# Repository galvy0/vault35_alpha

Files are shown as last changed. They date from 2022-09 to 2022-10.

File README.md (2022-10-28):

# Vault35 Alpha Stagger PCB
Alpha stagger version of Cain's Vault35 keyboard.  
Check out the original product and other awesome projects of Cain at [https://mechvault.net/](https://mechvault.net/).  

## PCB
### Layout Options
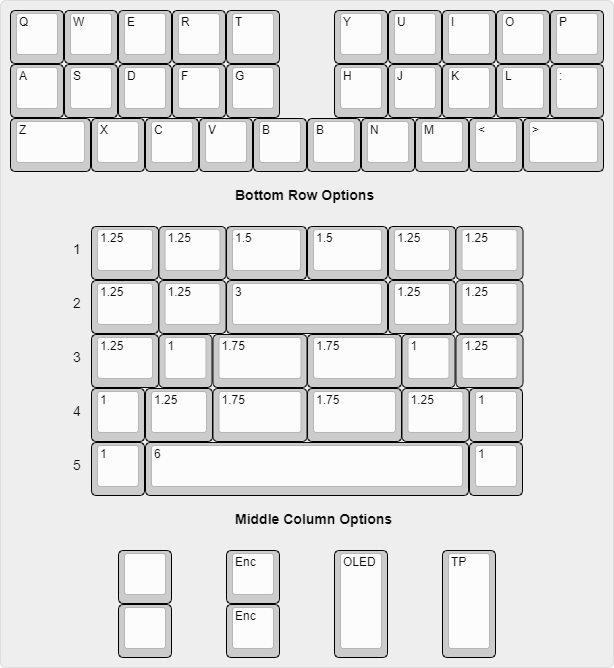
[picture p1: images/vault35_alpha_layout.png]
Layouts


### Middle Column Options
There are four options to fill in the space in the middle column: 1) two normal switches, 2) two encoders (or a combination of encoders and normal switches), 3) an OLED, and 4) a trackpoint module.  
For TP option, refer to my phoenix45 alpha stagger repo: https://github.com/galvy0/phoenix45_alpha

## Firmware
https://github.com/galvy0/qmk_firmware/tree/galvy/keyboards/galvy/vault35_alpha

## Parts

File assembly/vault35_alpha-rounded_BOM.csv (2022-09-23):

Id | Designator | Package | Quantity | Designation | Supplier and ref
1 | K_SPACE4,K_SPACE17,K_SPACE30,K_SPACE9,K_SPACE21,K_SPACE15,K_SPACE44,K_SPACE10,K_SPACE2,K_SPACE47,K_SPACE14,K_SPACE32,K_SPACE26,K_SPACE25,K_SPACE8,K_SPACE43,K_SPACE20,K_SPACE48,K_SPACE11,K_SPACE19,K_SPACE16,K_SPACE12,K_SPACE22,K_SPACE3,K_SPACE7,K_SPACE6,K_SPACE29,K_SPACE5,K_SPACE27,K_SPACE24,K_SPACE18,K_SPACE31,K_SPACE1,K_SPACE13 | MXOnly-1U-NoLED | 34 | KEYSW
2 | SW5 | PinHeader_1x02_P2.54mm_Vertical | 1 | SW_PUSH
3 | K_SPACE28,K_SPACE33,K_SPACE39,K_SPACE23 | MXOnly-1.5U-NoLED | 4 | KEYSW
4 | K_SPACE37,K_SPACE41,K_SPACE34,K_SPACE36,K_SPACE38,K_SPACE42 | MXOnly-1.25U-NoLED | 6 | KEYSW
5 | K_SPACE40 | MXOnly-3U-ReversedStabilizers-NoSwitch | 1 | KEYSW
6 | SW2,SW3 | RotaryEncoder_Alps_EC11E-Switch_Vertical_H20mm | 2 | RotaryEncoder_Switch
7 | SW6,SW1 | SW_SPST_SKQG_WithoutStem | 2 | SW_PUSH
8 | K_SPACE45,K_SPACE35 | MXOnly-1.75U-NoLED | 2 | KEYSW
9 | K_SPACE46 | MXOnly-6U-Centered-ReversedStabilizers-NoLED | 1 | KEYSW
10 | OL1 | OLED_v2 | 1 | OLED
11 | D_SPACE17,D_SPACE34,D_SPACE5,D_SPACE1,D_SPACE32,D_SPACE36,D_SPACE38,D_SPACE25,D_SPACE18,D_SPACE9,D_SPACE13,D_SPACE35,D_SPACE12,D_SPACE29,D_SPACE2,D_SPACE20,D_SPACE24,D_SPACE21,D_SPACE15,D_SPACE26,D_SPACE16,D_SPACE14,D_SPACE30,D_SPACE4,D_SPACE11,D_SPACE10,D_SPACE40,D_SPACE8,D_SPACE39,D_SPACE3,D_SPACE27,D_SPACE23,D_SPACE31,D_SPACE7,D_SPACE33,D_SPACE19,D_SPACE22,D_SPACE6 | D_SOD-123 | 38 | D
12 | X1 | Crystal_SMD_3225-4Pin_3.2x2.5mm_HandSoldering | 1 | Crystal_GND24_Small
13 | TP1 | TestPoint_THTPad_1.0x1.0mm_Drill0.5mm | 1 | TPCLK
14 | U1 | SOT-23-6 | 1 | SRV05-4
15 | UR5 | R_0805_2012Metric | 1 | 1M
16 | F1 | Fuse_1206_3216Metric_Pad1.42x1.75mm_HandSolder | 1 | Polyfuse_Small
17 | TP4 | TestPoint_THTPad_1.0x1.0mm_Drill0.5mm | 1 | TPDATA
18 | UR3,UR4 | R_0805_2012Metric | 2 | 5.1k
19 | U2 | QFN-44-1EP_7x7mm_P0.5mm_EP5.2x5.2mm_ThermalVias | 1 | ATmega32U4-M
20 | C2,C1 | C_0805_2012Metric | 2 | 22p
21 | C4 | C_0805_2012Metric | 1 | 10uF
22 | C10 | C_0805_2012Metric_Pad1.18x1.45mm_HandSolder | 1 | 2.2uF
23 | TP2 | TestPoint_THTPad_1.0x1.0mm_Drill0.5mm | 1 | TPVCC
24 | TP3 | TestPoint_THTPad_1.0x1.0mm_Drill0.5mm | 1 | TPGND
25 | UR1,UR2 | R_0805_2012Metric | 2 | 22
26 | R2,R1 | R_0805_2012Metric | 2 | 10k
27 | TP5 | TestPoint_THTPad_1.0x1.0mm_Drill0.5mm | 1 | TPRST
28 | UR8 | R_0805_2012Metric_Pad1.20x1.40mm_HandSolder | 1 | 100k
29 | C6,C8,C5,C7 | C_0805_2012Metric | 4 | 0.1uf
30 | UR7,UR6 | R_0805_2012Metric_Pad1.20x1.40mm_HandSolder | 2 | 4.7k
31 | C3 | C_0805_2012Metric | 1 | 1uf
32 | C9 | C_0805_2012Metric | 1 | 4.7uF
33 | USB1 | HRO-TYPE-C-31-M-12-HandSoldering | 1 | HRO-TYPE-C-31-M-12
34 | J1 | IDC-Header_2x03_P2.54mm_Vertical | 1 | AVR-ISP-6

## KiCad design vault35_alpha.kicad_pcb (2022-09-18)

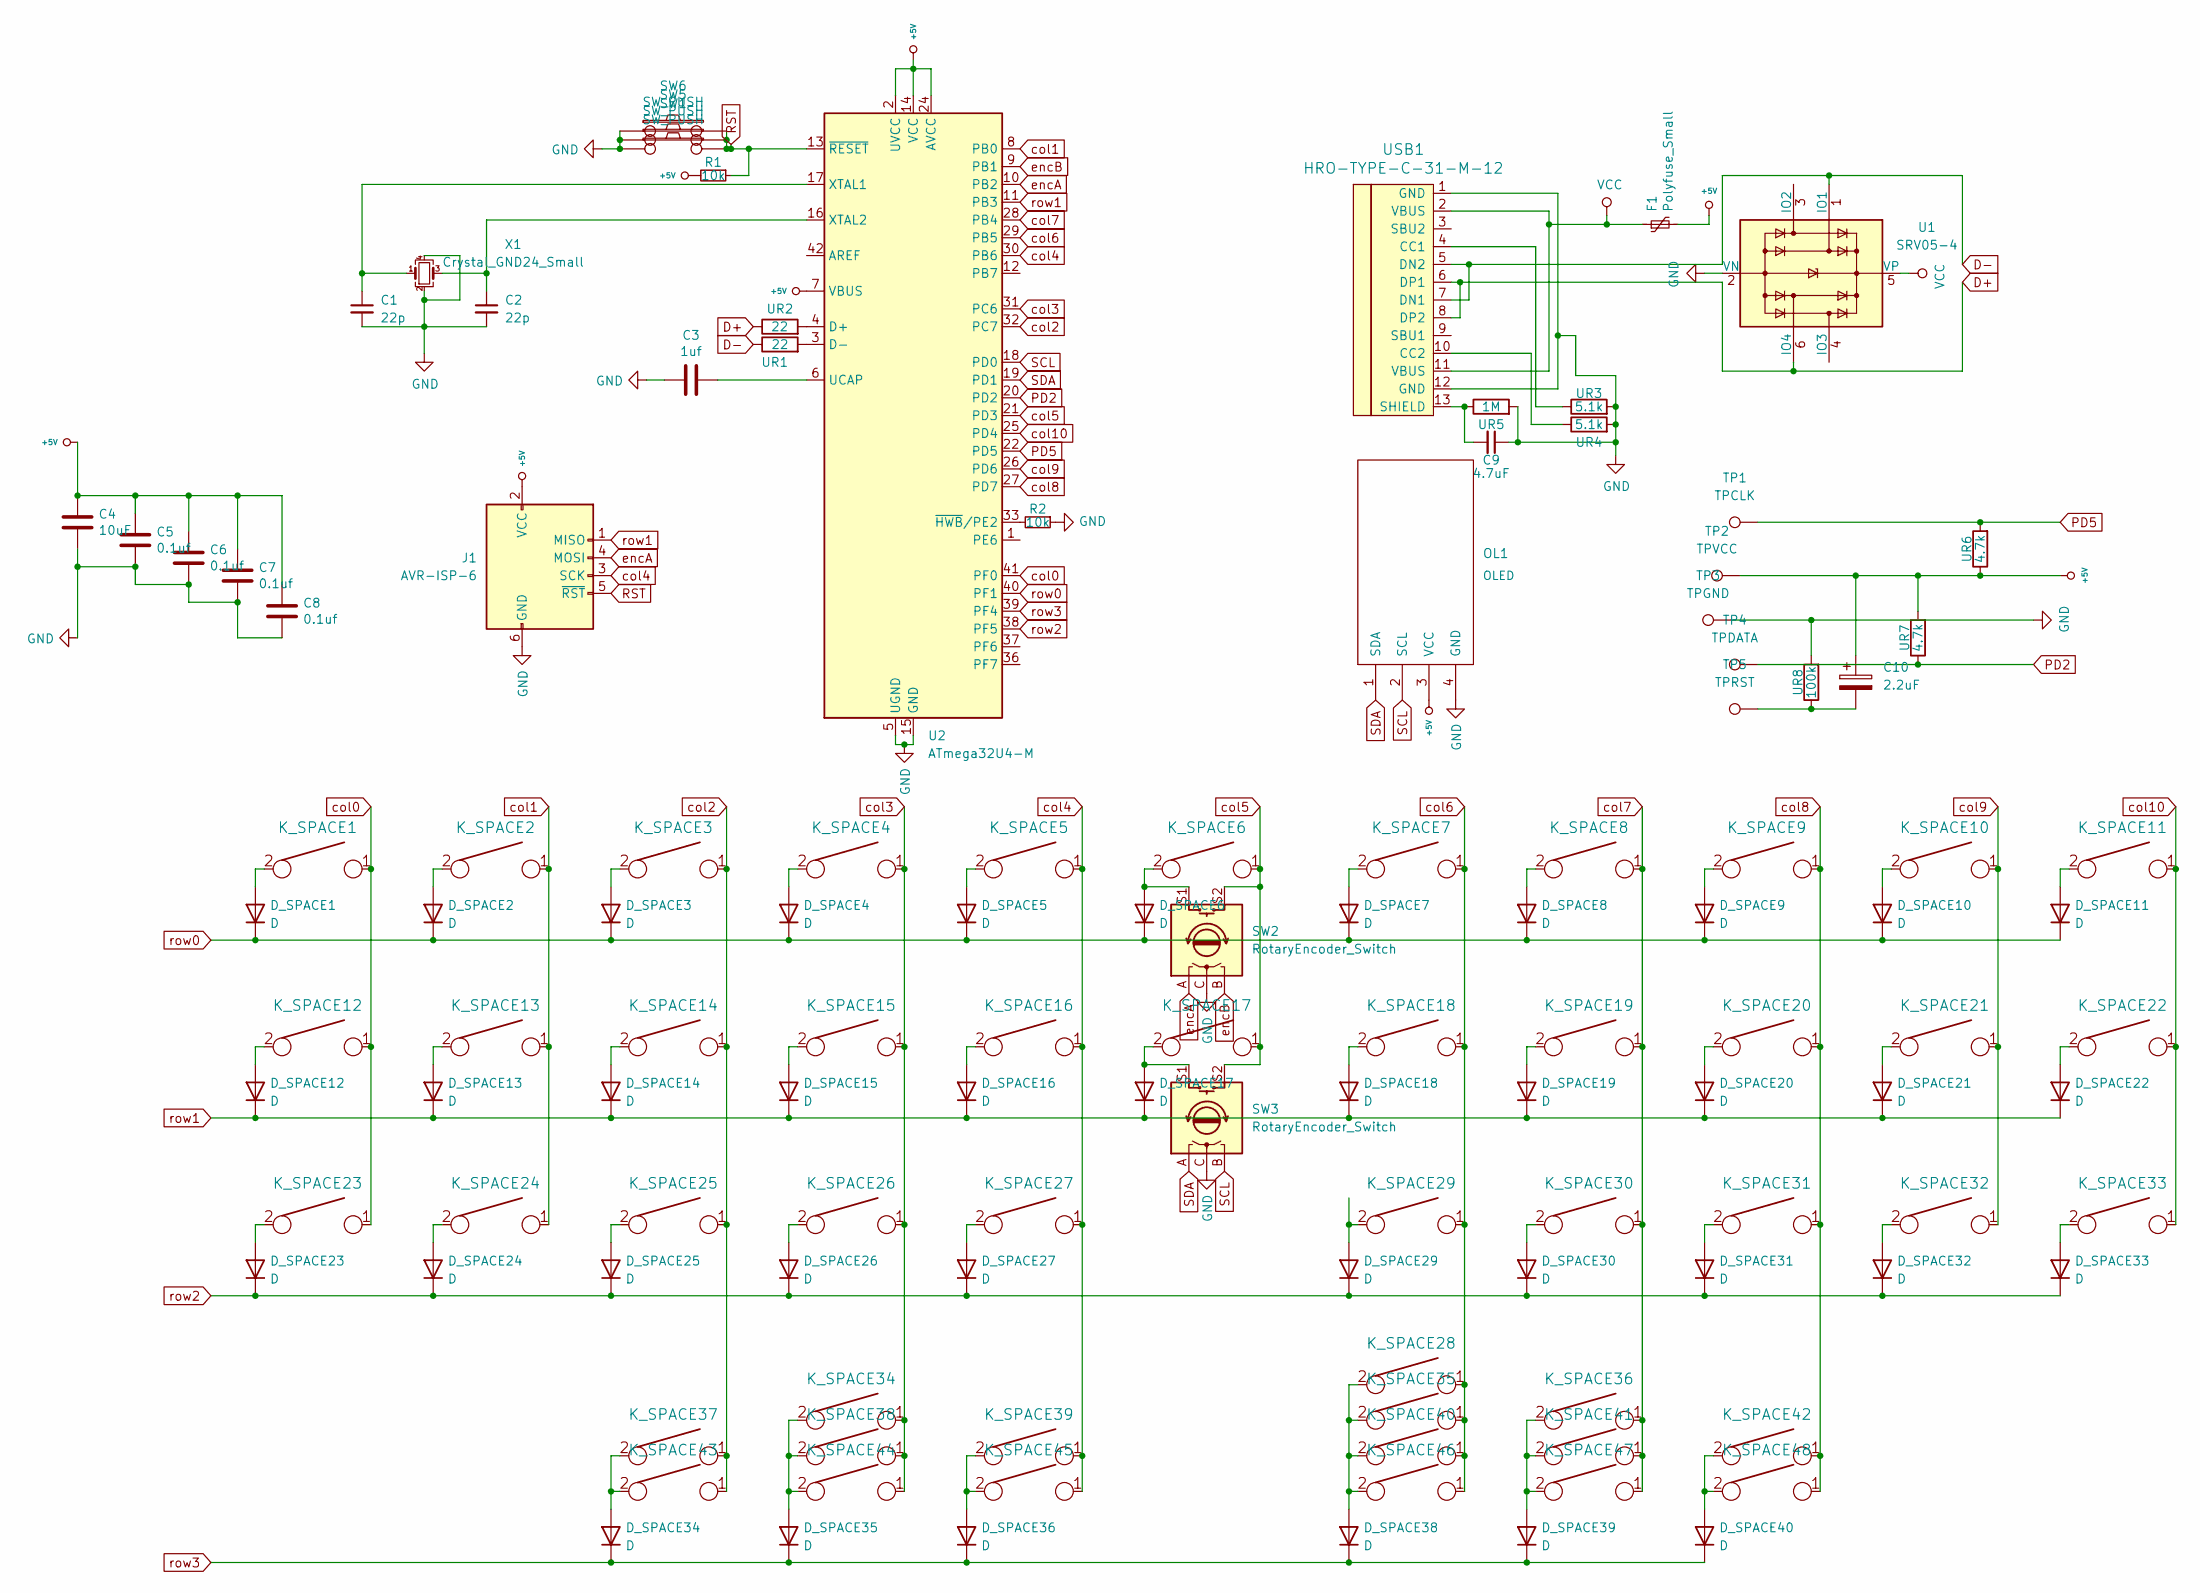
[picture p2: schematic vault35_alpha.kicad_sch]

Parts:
C1, C2: 22p; C_0805_2012Metric
C3: 1uf; C_0805_2012Metric
C4: 10uF; C_0805_2012Metric
C5, C6, C7, C8: 0.1uf; C_0805_2012Metric
C9: 4.7uF; C_0805_2012Metric
C10: 2.2uF; C_0805_2012Metric_Pad1.18x1.45mm_HandSolder
D_SPACE1, D_SPACE2, D_SPACE3, D_SPACE4, D_SPACE5, D_SPACE6, D_SPACE7, D_SPACE8, D_SPACE9, D_SPACE10, D_SPACE11, D_SPACE12, D_SPACE13, D_SPACE14, D_SPACE15, D_SPACE16, D_SPACE17, D_SPACE18, D_SPACE19, D_SPACE20, D_SPACE21, D_SPACE22, D_SPACE23, D_SPACE24, D_SPACE25, D_SPACE26, D_SPACE27, D_SPACE29, D_SPACE30, D_SPACE31, D_SPACE32, D_SPACE33, D_SPACE34, D_SPACE35, D_SPACE36, D_SPACE38, D_SPACE39, D_SPACE40: D; D_SOD-123
F1: Polyfuse_Small; Fuse_1206_3216Metric_Pad1.42x1.75mm_HandSolder
J1: AVR-ISP-6; IDC-Header_2x03_P2.54mm_Vertical
K_SPACE1, K_SPACE2, K_SPACE3, K_SPACE4, K_SPACE5, K_SPACE6, K_SPACE7, K_SPACE8, K_SPACE9, K_SPACE10, K_SPACE11, K_SPACE12, K_SPACE13, K_SPACE14, K_SPACE15, K_SPACE16, K_SPACE17, K_SPACE18, K_SPACE19, K_SPACE20, K_SPACE21, K_SPACE22, K_SPACE24, K_SPACE25, K_SPACE26, K_SPACE27, K_SPACE29, K_SPACE30, K_SPACE31, K_SPACE32, K_SPACE43, K_SPACE44, K_SPACE47, K_SPACE48: KEYSW; MXOnly-1U-NoLED
K_SPACE23, K_SPACE28, K_SPACE33, K_SPACE39: KEYSW; MXOnly-1.5U-NoLED
K_SPACE34, K_SPACE36, K_SPACE37, K_SPACE38, K_SPACE41, K_SPACE42: KEYSW; MXOnly-1.25U-NoLED
K_SPACE35, K_SPACE45: KEYSW; MXOnly-1.75U-NoLED
K_SPACE40: KEYSW; MXOnly-3U-ReversedStabilizers-NoSwitch
K_SPACE46: KEYSW; MXOnly-6U-Centered-ReversedStabilizers-NoLED
OL1: OLED; OLED_v2
R1, R2: 10k; R_0805_2012Metric
SW1, SW6: SW_PUSH; SW_SPST_SKQG_WithoutStem
SW2, SW3: RotaryEncoder_Switch; RotaryEncoder_Alps_EC11E-Switch_Vertical_H20mm
SW5: SW_PUSH; PinHeader_1x02_P2.54mm_Vertical
TP1: TPCLK; TestPoint_THTPad_1.0x1.0mm_Drill0.5mm
TP2: TPVCC; TestPoint_THTPad_1.0x1.0mm_Drill0.5mm
TP3: TPGND; TestPoint_THTPad_1.0x1.0mm_Drill0.5mm
TP4: TPDATA; TestPoint_THTPad_1.0x1.0mm_Drill0.5mm
TP5: TPRST; TestPoint_THTPad_1.0x1.0mm_Drill0.5mm
U1: SRV05-4; SOT-23-6
U2: ATmega32U4-M; QFN-44-1EP_7x7mm_P0.5mm_EP5.2x5.2mm_ThermalVias
UR1, UR2: 22; R_0805_2012Metric
UR3, UR4: 5.1k; R_0805_2012Metric
UR5: 1M; R_0805_2012Metric
UR6, UR7: 4.7k; R_0805_2012Metric_Pad1.20x1.40mm_HandSolder
UR8: 100k; R_0805_2012Metric_Pad1.20x1.40mm_HandSolder
USB1: HRO-TYPE-C-31-M-12; HRO-TYPE-C-31-M-12-HandSoldering
X1: Crystal_GND24_Small; Crystal_SMD_3225-4Pin_3.2x2.5mm_HandSoldering

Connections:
+5V: C4.1, C5.1, C6.1, C7.1, C8.1, C10.1, F1.2, J1.2 (VCC), OL1.3 (VCC), R1.2, TP2.1, U2.2 (UVCC), U2.7 (VBUS), U2.14 (VCC), U2.24 (AVCC), U2.34 (VCC), U2.44 (AVCC), UR6.1, UR7.2
D+: U1.6 (IO4), UR1.1, USB1.6 (DP1), USB1.8 (DP2)
D-: U1.1 (IO1), UR2.1, USB1.5 (DN2), USB1.7 (DN1)
GND: C1.2, C2.2, C3.2, C4.2, C5.2, C6.2, C7.2, C8.2, C9.1, J1.6 (GND), OL1.4 (GND), R2.1, SW1.1, SW2.C, SW3.C, SW5.1, SW6.1, TP3.1, U1.2 (VN), U2.5 (UGND), U2.15 (GND), U2.23 (GND), U2.35 (GND), U2.43 (GND), U2.45 (GND), UR3.2, UR4.2, UR5.2, UR8.2, USB1.1 (GND), USB1.12 (GND), X1.2, X1.4
unnamed: C1.1, U2.17 (XTAL1), X1.1
unnamed: C2.1, U2.16 (XTAL2), X1.3
unnamed: C3.1, U2.6 (UCAP)
unnamed: C9.2, UR5.1, USB1.13 (SHIELD)
unnamed: C10.2, TP5.1, UR8.1
unnamed: D_SPACE1.2 (A), K_SPACE1.2
unnamed: D_SPACE2.2 (A), K_SPACE2.2
unnamed: D_SPACE3.2 (A), K_SPACE3.2
unnamed: D_SPACE4.2 (A), K_SPACE4.2
unnamed: D_SPACE5.2 (A), K_SPACE5.2
unnamed: D_SPACE6.2 (A), K_SPACE6.2, SW2.S1
unnamed: D_SPACE7.2 (A), K_SPACE7.2
unnamed: D_SPACE8.2 (A), K_SPACE8.2
unnamed: D_SPACE9.2 (A), K_SPACE9.2
unnamed: D_SPACE10.2 (A), K_SPACE10.2
unnamed: D_SPACE11.2 (A), K_SPACE11.2
unnamed: D_SPACE12.2 (A), K_SPACE12.2
unnamed: D_SPACE13.2 (A), K_SPACE13.2
unnamed: D_SPACE14.2 (A), K_SPACE14.2
unnamed: D_SPACE15.2 (A), K_SPACE15.2
unnamed: D_SPACE16.2 (A), K_SPACE16.2
unnamed: D_SPACE17.2 (A), K_SPACE17.2, SW3.S1
unnamed: D_SPACE18.2 (A), K_SPACE18.2
unnamed: D_SPACE19.2 (A), K_SPACE19.2
unnamed: D_SPACE20.2 (A), K_SPACE20.2
unnamed: D_SPACE21.2 (A), K_SPACE21.2
unnamed: D_SPACE22.2 (A), K_SPACE22.2
unnamed: D_SPACE23.2 (A), K_SPACE23.2
unnamed: D_SPACE24.2 (A), K_SPACE24.2
unnamed: D_SPACE25.2 (A), K_SPACE25.2
unnamed: D_SPACE26.2 (A), K_SPACE26.2
unnamed: D_SPACE27.2 (A), K_SPACE27.2
unnamed: D_SPACE29.2 (A), K_SPACE29.2
unnamed: D_SPACE30.2 (A), K_SPACE30.2
unnamed: D_SPACE31.2 (A), K_SPACE31.2
unnamed: D_SPACE32.2 (A), K_SPACE32.2
unnamed: D_SPACE33.2 (A), K_SPACE33.2
unnamed: D_SPACE34.2 (A), K_SPACE37.2, K_SPACE43.2
unnamed: D_SPACE35.2 (A), K_SPACE34.2, K_SPACE38.2, K_SPACE44.2
unnamed: D_SPACE36.2 (A), K_SPACE39.2, K_SPACE45.2
unnamed: D_SPACE38.2 (A), K_SPACE28.2, K_SPACE35.2, K_SPACE40.2, K_SPACE46.2
unnamed: D_SPACE39.2 (A), K_SPACE36.2, K_SPACE41.2, K_SPACE47.2
unnamed: D_SPACE40.2 (A), K_SPACE42.2, K_SPACE48.2
unnamed: R2.2, U2.33 (~HWB/PE2)
unnamed: U2.3 (D-), UR2.2
unnamed: U2.4 (D+), UR1.2
unnamed: UR3.1, USB1.4 (CC1)
unnamed: UR4.1, USB1.10 (CC2)
PD2: TP4.1, U2.20 (PD2), UR7.1
PD5: TP1.1, U2.22 (PD5), UR6.2
RST: J1.5 (~RST), R1.1, SW1.2, SW5.2, SW6.2, U2.13 (~RESET)
SCL: OL1.2 (SCL), SW3.B, U2.18 (PD0)
SDA: OL1.1 (SDA), SW3.A, U2.19 (PD1)
VCC: F1.1, U1.5 (VP), USB1.2 (VBUS), USB1.11 (VBUS)
col0: K_SPACE1.1, K_SPACE12.1, K_SPACE23.1, U2.41 (PF0)
col1: K_SPACE2.1, K_SPACE13.1, K_SPACE24.1, U2.8 (PB0)
col2: K_SPACE3.1, K_SPACE14.1, K_SPACE25.1, K_SPACE37.1, K_SPACE43.1, U2.32 (PC7)
col3: K_SPACE4.1, K_SPACE15.1, K_SPACE26.1, K_SPACE34.1, K_SPACE38.1, K_SPACE44.1, U2.31 (PC6)
col4: J1.3 (SCK), K_SPACE5.1, K_SPACE16.1, K_SPACE27.1, K_SPACE39.1, K_SPACE45.1, U2.30 (PB6)
col5: K_SPACE6.1, K_SPACE17.1, SW2.S2, SW3.S2, U2.21 (PD3)
col6: K_SPACE7.1, K_SPACE18.1, K_SPACE28.1, K_SPACE29.1, K_SPACE35.1, K_SPACE40.1, K_SPACE46.1, U2.29 (PB5)
col7: K_SPACE8.1, K_SPACE19.1, K_SPACE30.1, K_SPACE36.1, K_SPACE41.1, K_SPACE47.1, U2.28 (PB4)
col8: K_SPACE9.1, K_SPACE20.1, K_SPACE31.1, K_SPACE42.1, K_SPACE48.1, U2.27 (PD7)
col9: K_SPACE10.1, K_SPACE21.1, K_SPACE32.1, U2.26 (PD6)
col10: K_SPACE11.1, K_SPACE22.1, K_SPACE33.1, U2.25 (PD4)
encA: J1.4 (MOSI), SW2.A, U2.10 (PB2)
encB: SW2.B, U2.9 (PB1)
row0: D_SPACE1.1 (K), D_SPACE2.1 (K), D_SPACE3.1 (K), D_SPACE4.1 (K), D_SPACE5.1 (K), D_SPACE6.1 (K), D_SPACE7.1 (K), D_SPACE8.1 (K), D_SPACE9.1 (K), D_SPACE10.1 (K), D_SPACE11.1 (K), U2.40 (PF1)
row1: D_SPACE12.1 (K), D_SPACE13.1 (K), D_SPACE14.1 (K), D_SPACE15.1 (K), D_SPACE16.1 (K), D_SPACE17.1 (K), D_SPACE18.1 (K), D_SPACE19.1 (K), D_SPACE20.1 (K), D_SPACE21.1 (K), D_SPACE22.1 (K), J1.1 (MISO), U2.11 (PB3)
row2: D_SPACE23.1 (K), D_SPACE24.1 (K), D_SPACE25.1 (K), D_SPACE26.1 (K), D_SPACE27.1 (K), D_SPACE29.1 (K), D_SPACE30.1 (K), D_SPACE31.1 (K), D_SPACE32.1 (K), D_SPACE33.1 (K), U2.38 (PF5)
row3: D_SPACE34.1 (K), D_SPACE35.1 (K), D_SPACE36.1 (K), D_SPACE38.1 (K), D_SPACE39.1 (K), D_SPACE40.1 (K), U2.39 (PF4)

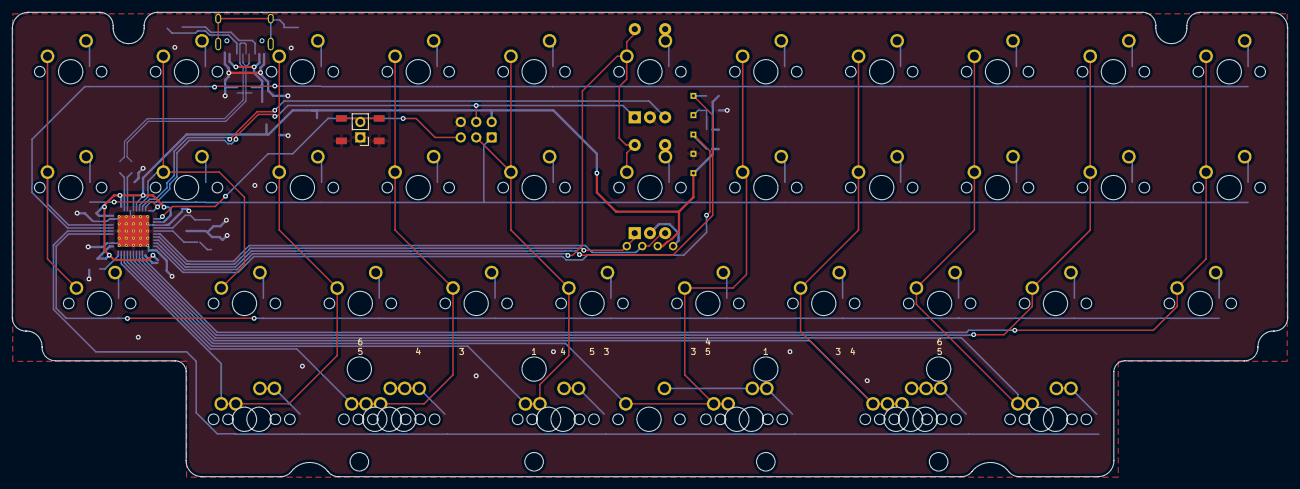
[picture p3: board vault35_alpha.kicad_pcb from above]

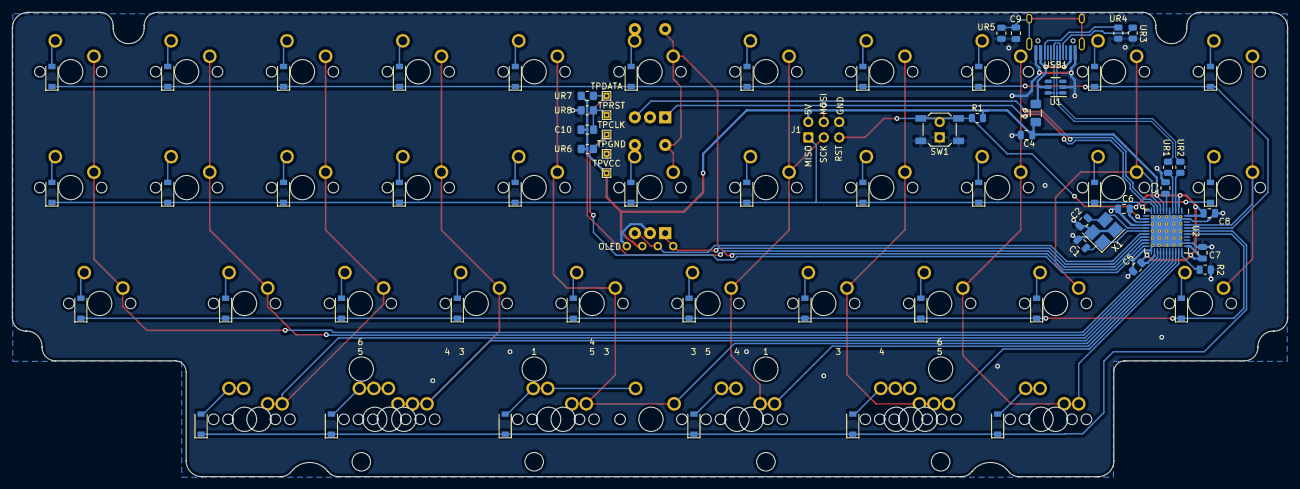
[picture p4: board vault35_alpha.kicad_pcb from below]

Board: 2 copper layers, 209.7 x 76.4 mm, 123 parts (70 on the bottom side), 75 nets.

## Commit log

2022-07-15 init alpha design
    [vault35_alpha.kicad_pcb, vault35_alpha.kicad_sch]
2022-09-18 update with TP, alpha stagger
    [vault35_alpha.kicad_pcb, vault35_alpha.kicad_sch]
2022-10-28 Update Plates
